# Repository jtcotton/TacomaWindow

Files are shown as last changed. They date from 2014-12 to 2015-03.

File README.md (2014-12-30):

TacomaWindow
============

Mechanism to power the sliding rear window in a Tacoma

This has recently been converted to a leadscrew approach from a rack and pinion.  

To build this project, you will need access to a 3d printer with a build volume of at least 4x4x4 and the 
ability to print in Nylon or ABS. Do NOT use PLA, it will melt in your truck. 

Build of Materials  (specifics to follow)

1 gear head motor (TBD)
9 meters of Nylon filament
1 M8 threaded rod, 16 inches
4 m8 washers
1 m8 locknut
1 m8 normal nut
1 Arduino or clone
2 micro switches
1 NO switch
1 H-Bridge

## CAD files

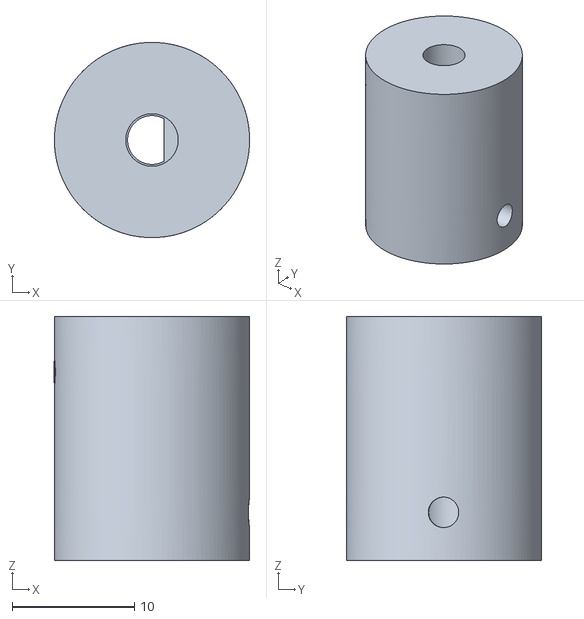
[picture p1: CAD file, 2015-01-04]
Motor_Coupler/STL_Files/Motor_Coupler.stl
16.0 x 16.0 x 20.0

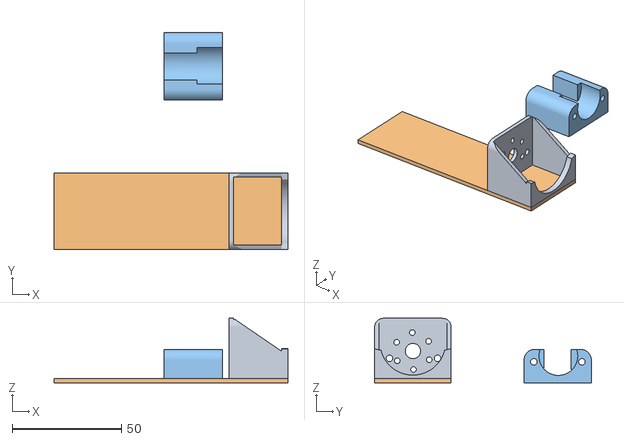
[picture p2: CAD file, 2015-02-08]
Multi_Motor_Housing/STL_Files/Multi_Motor_Housing.stl
107.0 x 99.1 x 29.5

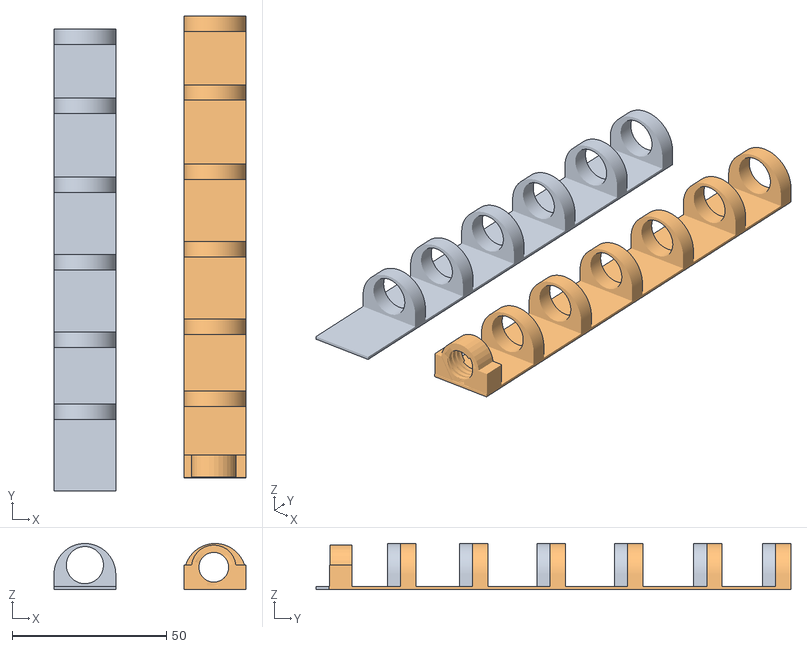
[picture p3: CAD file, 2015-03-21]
Window_Attachment/STL_Files/Window_Attachment.stl
62.2 x 153.8 x 14.9

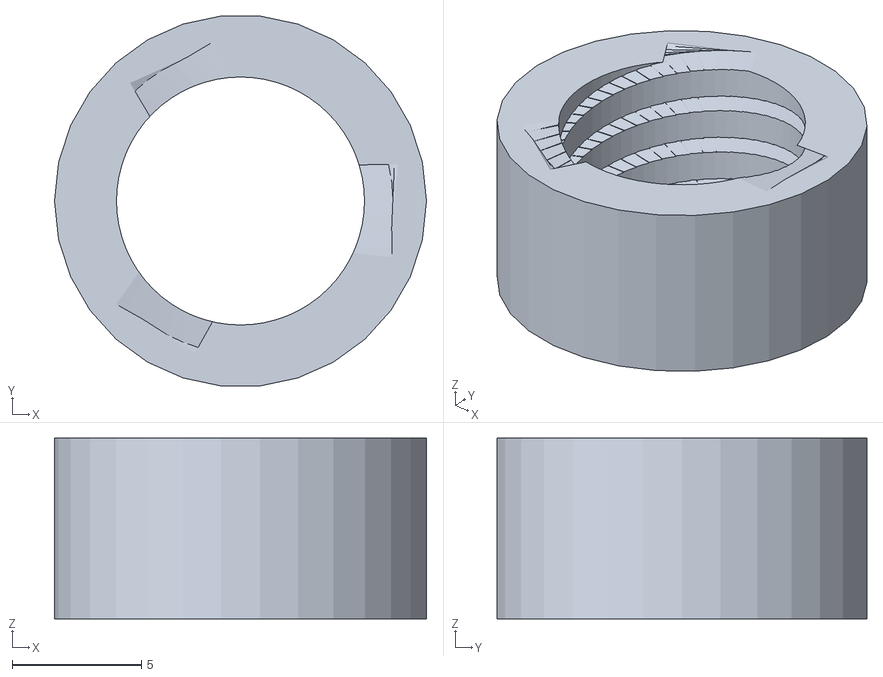
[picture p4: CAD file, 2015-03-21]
Lead_Screw/STL_Files/lead_Screw_nut.stl
14.4 x 14.3 x 7.00

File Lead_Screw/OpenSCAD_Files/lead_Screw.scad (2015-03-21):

rod_length = 100; 	// the length of the threaded rod

thread_count = 3;	// number of threads
thread_width = 3;	// the width of each thread
thread_depth = 5;	// the radius of each thread
	// If width is set to exactly twice the depth,
	// you'll end up with a triangular thread profile.
	// However, the resulting radius of the threaded
	// rod will no longer conform to thread_depth.
	
thread_facet_factor = 1024;	// thread facets/slices/resolution. 256 or greater works well.
thread_facets = (rod_length/100)*thread_facet_factor;	

thread_pitch = 0.18;	// turns per mm; this sets twist_degrees.
twist_degrees = (rod_length*thread_pitch)*360;

base_radius = 4;	// outer radius of the central cylinder 
base_facets = 64;	// facets of the central cylinder. Recommended to set this 32 or higher.

inner_radius = 2.5;	// radius of the central hole
inner_facets = 12;	// facets of the central hole; set this to 6 for a hexagonal hole, set it to some high value like 20 for a circular hole.

nut_height = 7;	// the height of the nut
nut_radius = 6;	// the radius of the nut
nut_facets = 30;		// number of nut facets; set this to 6 for a hexagonal nut, 4 for square, 30+ for round.	
nut_scale = 1.2;	// scale the nut by this much in the X and Y axes, in order to fit on the thread cleanly. A value of 1.1 works well.

rotate_increment = 360 / thread_count;  // the angle by which to rotate each thread (don't change this unless you want an asymmetrical result)

//// Generation options ////
shownut = 1;		// generate a nut
showthread = 0;		// generate a threaded rod
showthreadplate = 0;	// generate a plate of multiple threaded rods
plate_number = 2;	// when showthreadplate is set to 1, the number of rods generated will equal this number squared.

module thread()
{
for ( i = [1 : thread_count] ) {
	linear_extrude(height=rod_length, center=true, convexity=10, twist=twist_degrees, slices=thread_facets)
	rotate([0,0,(rotate_increment * i)]) {
		translate([-(thread_width/2),0]) {
		square(size = [thread_width,thread_depth], center=false);
		}
	}
}	

linear_extrude(height=rod_length, center=true, convexity=10, twist=0) {
	circle(r=base_radius,$fn=base_facets);
	}
}

module threadbolt()
{
	difference()
	{
		thread();
		translate(v=[0,0,-rod_length])
			cylinder(h=(rod_length*2),r=inner_radius,$fn=inner_facets);
	}
}

module nut()
{
	scale(v=[nut_scale,nut_scale,1])
	difference()
	{
		cylinder(h=nut_height, r=nut_radius, $fn=nut_facets);
		thread();
	}
}

module main()
{
	if(showthreadplate == 1)
	{
		for(n=[1:plate_number])
			for(m=[1:plate_number])
				translate(v=[n*(thread_depth*2.5),m*(thread_depth*2.5),0])
				threadbolt();
	}
	if(shownut == 1)
	{
		nut();
	}
	if(showthread == 1)
	{
		threadbolt();
	}
}

main();

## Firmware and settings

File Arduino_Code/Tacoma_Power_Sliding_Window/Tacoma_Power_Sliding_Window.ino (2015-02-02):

/*
Title:		Toyota Tacoma Power Sliding Window Arduino Code
Author:		Jonathan Cotton (aka TXCotton)
Date:		01/31/2015
Attribution:
		Original idea and R&D by "scratch" on tacomaworld.com
		http://www.tacomaworld.com/forum/2nd-gen-tacomas/356628-power-sliding-window-again.html
Description:	
		This code reads a momentary ON-OFF-ON rocker switch & 2 limit switches.  Using these
		inputs, it controls a DC Motor to open / close the rear sliding window.  The rocker
		switch acts as an automatic open / close switch, allowing the user to press and release,
		while the window opens or closes completely without having to hold down the switch for
		the entire duration of travel, much like modern auto down power windows.  Pressing the
		opposite rocker switch direction during movement will stop the movement completely but
		will not change direction (e.g.: while closing, if open is pressed, the window will stop).

		This assumes the following hardware:
		*  3D Printed Mounting Brackets & Leadscrew (https://github.com/scratchhax/TacomaWindow)
		*  Momentary ON-OFF-ON switch (ex: http://www.amazon.com/gp/product/B00H8RD000)
		*  L293D H-Bridge Motor Driver (or compatible such as SN754410 from https://www.sparkfun.com/products/315)
		*  Arduino Pro Mini 5V (https://www.sparkfun.com/products/11113)
		*  L7805 5V Regulator (https://www.sparkfun.com/products/107)
		*  2 x D2F-L-D3 or similar Limit Switches (http://www.digikey.com/product-detail/en/D2F-L-D3/D2F-L-D3-ND)
		*  300RPM DC Motor (http://www.amazon.com/gp/product/B0080DL25Q)
		*  3mm to 5mm Motor Shaft Coupler (http://www.amazon.com/gp/product/B00KHTVZ1M)
		*  10-24 threaded rod, nylon lock nuts, washers
		*  Misc wire, protoboard, screw terminals, screws, solder, etc...
*/

/**********************************************************************************************
Type Definitions
**********************************************************************************************/
enum dir {
  OFF,
  OPEN,
  CLOSE
};


/**********************************************************************************************
Variable Declarations
**********************************************************************************************/
int enaPin = 2;
int in1Pin = 3;
int in2Pin = 8;
int switchClosePin = 10;
int switchOpenPin = 11;
int limitClosePin = 12;
int limitOpenPin = 9;
dir state = OFF;


/**********************************************************************************************
Function Declarations
**********************************************************************************************/
void setup();
void loop();
void setState(dir newState);


/**********************************************************************************************
Configure I/O Pins when powered on.

Note:	All Input Pins are pulled up to VCC, so we are using inverse logic by pulling all Inputs
	to GND when the are activated.
**********************************************************************************************/
void setup()
{
  /********************************************************************************************
	L293D Connections:		Arduino Pro Mini Connections:	L7805 Connections:

	1	ENA			GND	GND			IN	Truck +12V
	2	In1			RAW	+5V			GND	GND
	3	Motor +			2	ENA			OUT	Arduino RAW
	4	GND			3	In1
	6	Motor -			8	In2
	7	In2			10	SwitchClose
	8	Truck +12V		11	SwitchOpen
	16	Truck +12V		12	LimitClose
					9	LimitOpen

	Switch Connections:		Limit Open Connections:		Limit Close Connections:

	Open	SwitchOpen(11)		NO	LimitOpen(9)		NO	LimitClose(12)
	COM	GND			COM	GND			COM	GND
	Close	SwitchClose(10)

  ********************************************************************************************/

  pinMode(enaPin, OUTPUT);
  pinMode(in1Pin, OUTPUT);
  pinMode(in2Pin, OUTPUT);
  pinMode(switchClosePin, INPUT_PULLUP);
  pinMode(switchOpenPin, INPUT_PULLUP);
  pinMode(limitClosePin, INPUT_PULLUP);
  pinMode(limitOpenPin, INPUT_PULLUP);
}


/**********************************************************************************************
Detect state changes in a loop
**********************************************************************************************/
void loop()
{
  /********************************************************************************************
	State Change Scenarios:

	LastState	LimitClose	LimitOpen	SwitchClose	SwitchOpen	NewState
	OFF		X		HIGH		X		LOW		OPEN		If Stopped & Open Button pressed & Not @ Open Limit, start opening
	OFF		HIGH		X		LOW		X		CLOSE		If Stopped & Close Button pressed & Not @ Close Limit, start Closing
	OPEN		X		X		LOW		X		OFF		If Opening & Close Button pressed, stop
	OPEN		X		LOW		X		X		OFF		If Opening & Opened limit reached, stop
	CLOSE		X		X		X		LOW		OFF		If Closing & Open Button pressed, stop
	CLOSE		LOW		X		X		X		OFF		If Closing & Closed limit reached, stop


	Note:	All Input Pins are pulled up to VCC (normally HIGH), so we are using inverse logic by connecting the Input
		to GND when activated so they show up as LOW.
  ********************************************************************************************/

  if (state == OFF && digitalRead(limitOpenPin) == HIGH && digitalRead(switchOpenPin) == LOW )
  {
    setState(OPEN);
  }
  else if (state == OFF && digitalRead(limitClosePin) == HIGH && digitalRead(switchClosePin) == LOW )
  {
    setState(CLOSE);
  }
  else if (state == OPEN && digitalRead(switchClosePin) == LOW )
  {
    setState(OFF);
  }
  else if (state == OPEN && digitalRead(limitOpenPin) == LOW )
  {
    setState(OFF);
  }
  else if (state == CLOSE && digitalRead(switchOpenPin) == LOW )
  {
    setState(OFF);
  }
  else if (state == CLOSE && digitalRead(limitClosePin) == LOW )
  {
    setState(OFF);
  }
}


/**********************************************************************************************
Set outputs based on new state
**********************************************************************************************/
void setState(dir newState)
{
  /********************************************************************************************
	State Output Definitions:

	ENA	In1	In2
	1	0	0	OFF
	1	1	0	OPEN
	1	0	1	CLOSE
  ********************************************************************************************/
  state = newState;
  if (newState == OFF)
  {
    digitalWrite(enaPin, HIGH);
    digitalWrite(in1Pin, LOW);
    digitalWrite(in2Pin, LOW);
    delay(500);
  }
  else if (newState == OPEN)
  {
    digitalWrite(enaPin, HIGH);
    digitalWrite(in1Pin, HIGH);
    digitalWrite(in2Pin, LOW);
  }
  else if (newState == CLOSE)
  {
    digitalWrite(enaPin, HIGH);
    digitalWrite(in1Pin, LOW);
    digitalWrite(in2Pin, HIGH);
  }
}

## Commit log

2014-12-27 converted rack to ibeam
    [Rack.stl]
2014-12-27 Added base servo guide
    [Base_servo_guide.stl]
2014-12-28 Guide with screw holes
    [Base_servo_guide.stl]
2014-12-28 More block adjustements
    dropped the servo rest down .3mm, created sliding mounts
    [Base_servo_guide.stl]
2014-12-28 Added top plate, ibeam to tbeam
    added the top plate, expanded the ibeam into a tbeam for additional
    support.
    [Base_servo_guide.stl, Base_servo_guide_one_piece.stl, Rack.stl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]
2014-12-28 All parts refactored
    Rebuilt the bottom rack to support bigger screws, beefed up the top
    guide and added sight holes, rebuilt the ibeam into a tbeam.
    [Base_servo_guide_one_piece.stl, Top_Servo_Guide_One_Piece.stl]
2014-12-28 Cleanup
    removed some gcode, moved servo holes around.
    [Base_servo_guide_one_piece.stl]
2014-12-28 strength improvements
    added 5mm to the top and bottom guides to address racking.
    [Top_Servo_Guide_One_Piece.stl]
2014-12-28 Rotated top guide
    The top guide doesn't print well if it has to use supports on the 5mm
    overhang. Rotated 90 degrees. will require more supports and a slower
    print, but only supports on non essential sections.
    [Top_Servo_Guide_One_Piece.stl]
2014-12-29 last changes
    last changes before switching over to screw drive. Rack and Pinion is
    working, but it looks like reliability is going to be an issue (gears
    are wearing fast) so I'm switching to a lead screw system.
2014-12-29 Initial Commit
    Created the motor coupler for a #8 threaded rod to a 2.3mm shaft DC
    motor
    [Motor_Coupler.stl]
2014-12-29 Add Motor housing
    Add first stab at the motor housing. Went with thicker material since
    this is plastic.
    [Motor_Housing.stl]
2014-12-29 Added Window attachment
    added the part that attaches to the window
    [Window_Attachment.stl]
2014-12-30 Create README.md
    Added outline for BOM
2014-12-30 Created slipper clutch
    converted the motor coupling into a slipper clutch. One half of the
    coupling complete in this commit.
2014-12-30 Slipper clutch test
    3 piece motor coupler with slipper clutch
2014-12-30 screw holes
    Bah, who needs screw holes.
2014-12-31 Uncomplicated things
    I always make things so much harder than they need to be. Reduced the
    part count on the slip clutch to the motor adapter and the clutch
    itself.
    [Slip_Clutch.stl]
2014-12-31 printed prototypes
    prototype coupler and clutch printed from these files and settings.
2015-01-01 Nylon shrinkage
    Working on different designs to try to keep the nylon from warping
    [Motor_Coupler.stl]
2015-01-03 Motor housing adjustments for small motor
    Going with the 16mm motor. Motor housing has been adjusted for that
    motor plus a recess for the coupler. Gussets for support
    [Motor_Housing.stl]
2015-01-03 motor coupler adapted for 3mm
    motor coupler shaft adapted for 3mm shaft with a single keyed edge.
    [Motor_Coupler.stl]
2015-01-04 Bye Bye slipper clutch
    Motor coupler is a solid coupler now, no more slipper
    [Motor_Coupler.stl]
2015-01-04 Added motor supports
    I can't find m.5 3mm screws anywhere, so I created supports that will
    push the motor into the mounting plate and remove the need for screws.
    Go me.
    [Motor_Coupler.stl, Motor_Housing.stl]
2015-01-04 Coupler support, captive nut
    Added a support for the motor coupler so if the set screw comes lose,
    the coupler won't come off. Switched the window mount to a captive #10
    nut, its faster, stronger and has less friction.
    [Motor_Housing.stl, Window_Attachment.stl]
2015-01-23 Multi_Motor_Commit
    Initial commit of the multimotor mount
    [Multi_Motor_Housing.stl]
2015-01-23 driver_board housing
    Added the housing for the driver board and arduino
    [Multi_Motor_Housing.stl]
2015-01-24 New mount
    Major changes to the motor housing. Added an adapter for the small
    motor, changed overall dimensions, rounded edges for strength.
2015-01-25 Motor Size adjustments
    tweaking the motor mount for a tighter fit
    [Multi_Motor_Housing.stl]
2015-01-28 lead screw conversion
    And now we're converting over to a printed leadscrew and relays instead
    of an arduino. Leadscrew folder and SCAD file checked in.
    [Multi_Motor_Housing.stl, lead_Screw.scad, lead_Screw_nut.stl]
2015-02-01 Adding Arduino Code
2015-02-02 Arduino Code fixes from Bench Test
    Boolean logic needed to be inverted due to Input Pull-ups. Using Input
    pull-up so we don’t need any external pull-up or down resistors.
    Added delay after turning off so we don’t double detect state change
    when changing from Open or Close states to Off.
    Changed Limit Open Pin to 9, 13 wasn’t working, might just be my
    Arduino.
    Added extra info about switch and limit switch connections.
    Wasn’t setting “state” global in setState function, should have been,
    doing it now.
    [Tacoma_Power_Sliding_Window.ino]
2015-02-02 final pitch adjustment
    Final pitch adjustment for the lead screw. This screw acts like a
    security bar when not powered and moves at 5mm per rotation
    [lead_Screw.scad, lead_Screw_nut.stl]
2015-02-02 err, I mean NOW it's final
    seriously. I think.
    [lead_Screw.scad, lead_Screw_nut.stl]
2015-02-07 Updated Assembled drawings with latest components.
    Updated Assembled drawings with latest components.
2015-02-08 I'm back baby
    Motor housing changes. modified the mount profile to strengthen it up.
    removed the electronics housing, will make that a module.
    [Multi_Motor_Housing.stl]
2015-02-08 Window mount refactor
    refactored the window mount to house the lead nut and rounded it out to
    make it purdy.
    [Window_Attachment.stl]
2015-02-08 cleanup slip clutch
    clean up, deleted slip clutch
    [Slip_Clutch.stl]
2015-02-08 cleanup motor housing
    cleanup, delete single motor housing
    [Motor_Housing.stl]
2015-02-08 Window wobble guide
    Modified the window mount to have guides to help cut down on wobble.
2015-02-09 still working on the window mount
    this is getting tedious. I can't tell if Im fighting my design or my
    printer.
2015-03-08 Rebuilt window mount
    Rebuilt the window mount to be much lower profile, should pass by the
    seats even with passengers now.
    [Window_Attachment.stl, lead_Screw_nut.stl]
2015-03-21 sync up
    just a sync up to make sure all changes are in place
    [Window_Attachment.stl, lead_Screw.scad, lead_Screw_nut.stl]
2015-04-12 Floating window mount
    Added floating window mount for SandMan614. bearing block fits 608
    bearing
2015-04-12 Added channel
    added a 20mm x 150mm c channel
